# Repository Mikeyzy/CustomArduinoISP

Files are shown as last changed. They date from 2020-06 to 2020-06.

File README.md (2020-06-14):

# CustomArduinoISP
Custom ArduinoISP Board with Voltage Selection

This is a custom designed ArduinoISP based AVR ISP board, with 5V/3V3 selection switch and pwoer dilivery switch, you need ArduinoISP software which is avaliable in Examples from Arduino IDE, you can download it from www.arduino.cc

you need Autodesk EAGLE to open the schematics.

the license only apply to the hardware design, since the software is not included.

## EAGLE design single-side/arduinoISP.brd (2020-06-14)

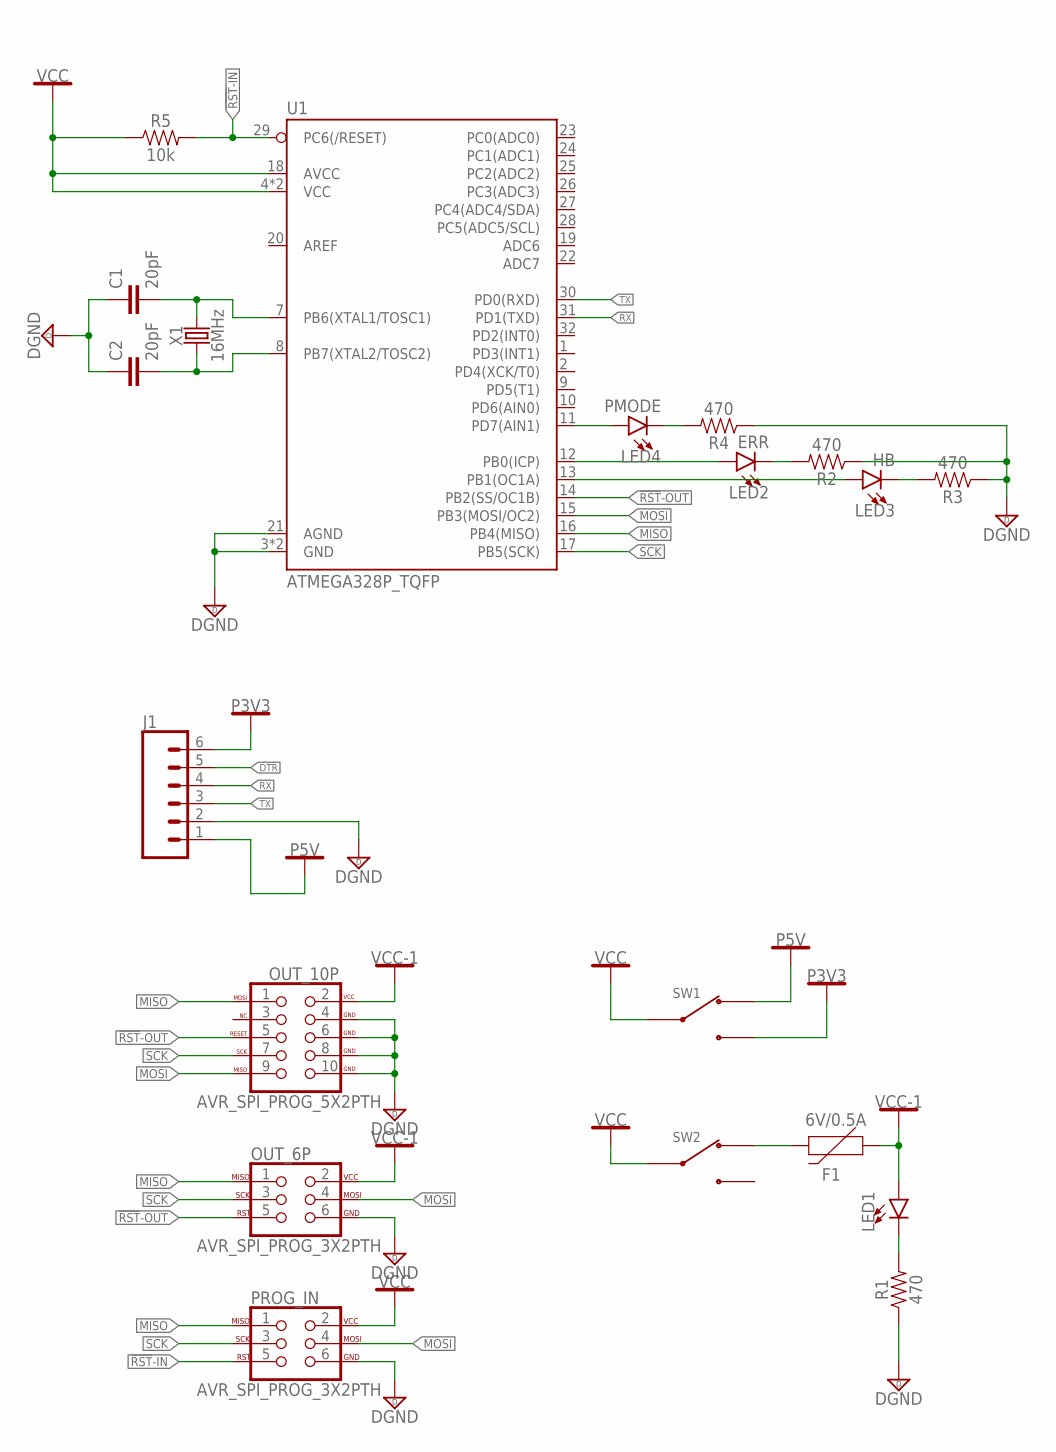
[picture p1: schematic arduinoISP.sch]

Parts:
C1, C2: 20pF; 0603
F1: 6V/0.5A; 1206
J1: CONN_06NO_SILK_NO_POP; 1X06_NO_SILK
LED1: LED3MM; LED_3MM
LED2: ERR; LED_3MM
LED3: HB; LED_3MM
LED4: PMODE; LED_3MM
OUT_6P: AVR_SPI_PROG_3X2PTH; 2X3
OUT_10P: AVR_SPI_PROG_5X2PTH; 2X5
PROG_IN: AVR_SPI_PROG_3X2PTH; 2X3
R1, R2, R3, R4: 470; 0603
R5: 10k; 0603
SW1, SW2: SW-SPDT_SS-12D02-VG4; SW_SS-12D10L5_FP
U1: ATMEGA328P_TQFP; TQFP32-08
X1: 16MHz; HC49US

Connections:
!RST!-IN: PROG_IN.5, R5.2, U1.29 (PC6(/RESET))
!RST!-OUT: OUT_6P.5, OUT_10P.5 (RESET), U1.14 (PB2(SS/OC1B))
DGND: C1.1, C2.1, J1.2, OUT_6P.6, OUT_10P.4 (GND), OUT_10P.6 (GND), OUT_10P.8 (GND), OUT_10P.10 (GND), PROG_IN.6, R1.1, R2.1, R3.1, R4.1, U1.3 (GND), U1.5 (GND), U1.21 (AGND)
DTR: J1.5
MISO: OUT_6P.1, OUT_10P.1 (MOSI), PROG_IN.1, U1.16 (PB4(MISO))
MOSI: OUT_6P.4, OUT_10P.9 (MISO), PROG_IN.4, U1.15 (PB3(MOSI/OC2))
unnamed: LED1.K (C), R1.2
unnamed: LED2.K (C), R2.2
unnamed: LED2.A, U1.12 (PB0(ICP))
unnamed: LED3.K (C), R3.2
unnamed: LED4.K (C), R4.2
unnamed: LED3.A, U1.13 (PB1(OC1A))
unnamed: LED4.A, U1.11 (PD7(AIN1))
unnamed: C1.2, U1.7 (PB6(XTAL1/TOSC1)), X1.2
unnamed: C2.2, U1.8 (PB7(XTAL2/TOSC2)), X1.1
unnamed: F1.2, SW2.P$1 (A)
P3V3: J1.6, SW1.P$3 (B)
P5V: J1.1, SW1.P$1 (A)
RX: J1.4, U1.31 (PD1(TXD))
SCK: OUT_6P.3, OUT_10P.7 (SCK), PROG_IN.3, U1.17 (PB5(SCK))
TX: J1.3, U1.30 (PD0(RXD))
VCC: PROG_IN.2, R5.1, SW1.P$2 (COM), SW2.P$2 (COM), U1.4 (VCC), U1.6 (VCC), U1.18 (AVCC)
VCC1: F1.1, LED1.A, OUT_6P.2, OUT_10P.2 (VCC)

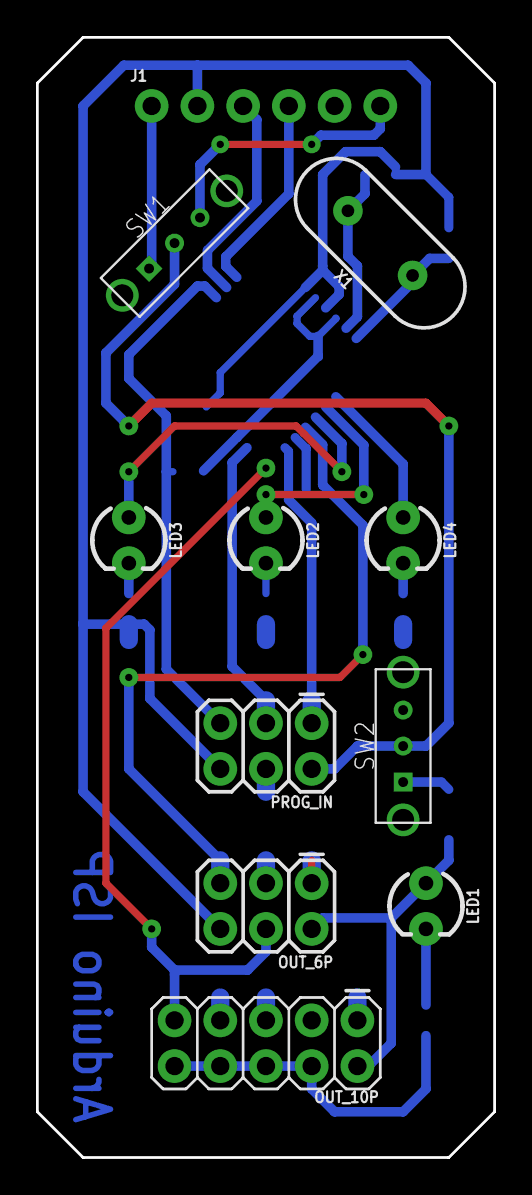
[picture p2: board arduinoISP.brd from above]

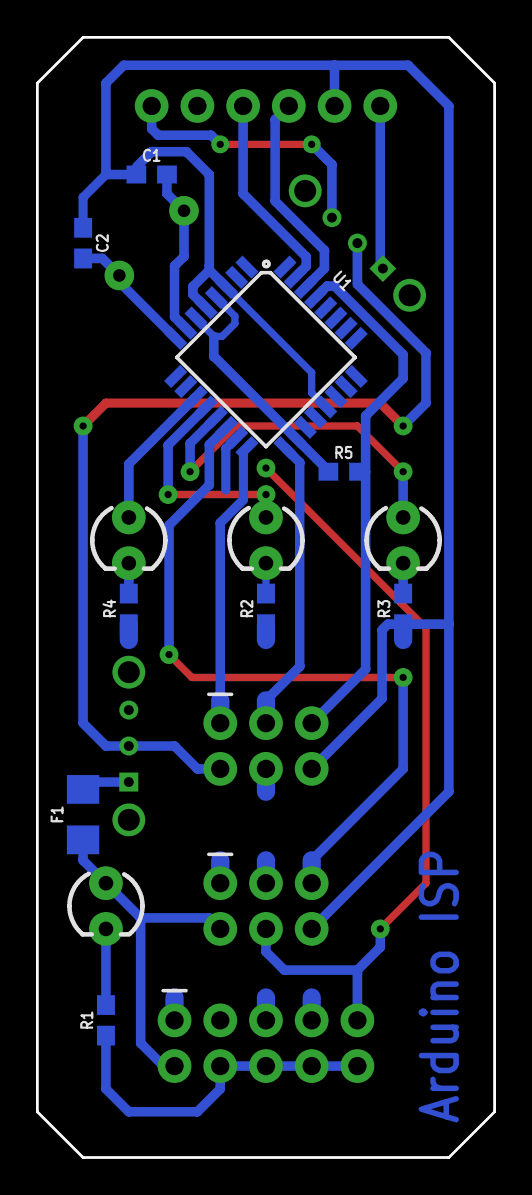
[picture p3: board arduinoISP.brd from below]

Board: 2 copper layers, 25.4 x 62.2 mm, 20 parts (9 on the bottom side), 22 nets.

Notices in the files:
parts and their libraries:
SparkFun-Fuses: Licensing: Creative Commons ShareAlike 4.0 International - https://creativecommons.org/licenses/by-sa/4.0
